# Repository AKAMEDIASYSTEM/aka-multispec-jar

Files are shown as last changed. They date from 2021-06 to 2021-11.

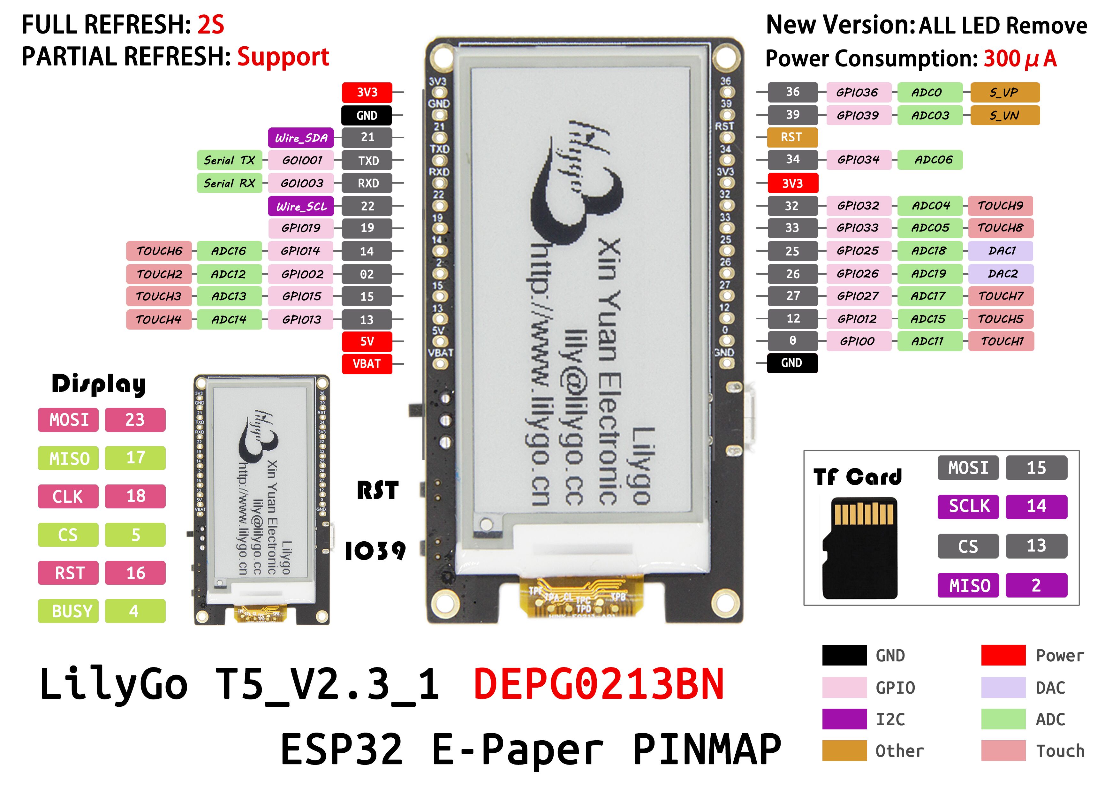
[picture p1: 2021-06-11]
LILYGO-epaper-pinout-graphic.jpg

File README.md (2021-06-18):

EINK STARTER MONITOR
===

See full blogpost [here](https://hi-hi-hi.com/food/projects/2021/06/18/jar.html)

Tracks height of starter with a VL6180 i2c distance sensor, and CO2/temperature/humidity with an SCD30. A small MOSFET circuit drives a little fan to more consistently sample the CO2.

Built around the LILYGO EINK [module](https://www.aliexpress.com/item/32869729970.html)

BOM
-------

- LILYGO EINK [module](https://www.aliexpress.com/item/32869729970.html)
- Adafruit Qwiic [SCD30](https://www.adafruit.com/product/4867)
- Adafruit [VL6180](https://www.adafruit.com/product/3316)
- 2N7000 N-Channel [MOSFET](https://www.digikey.com/en/products/detail/fairchild-semiconductor/2N7000/13430333)
- 420mAh [LiPo](https://www.adafruit.com/product/4236)
- wee tiny Fan ([this](https://www.sparkfun.com/products/15504) or any equivalent, smaller the better)
- M2 screws, 12 to 20mm long, and nuts
- Peanut butter container and 2 lids

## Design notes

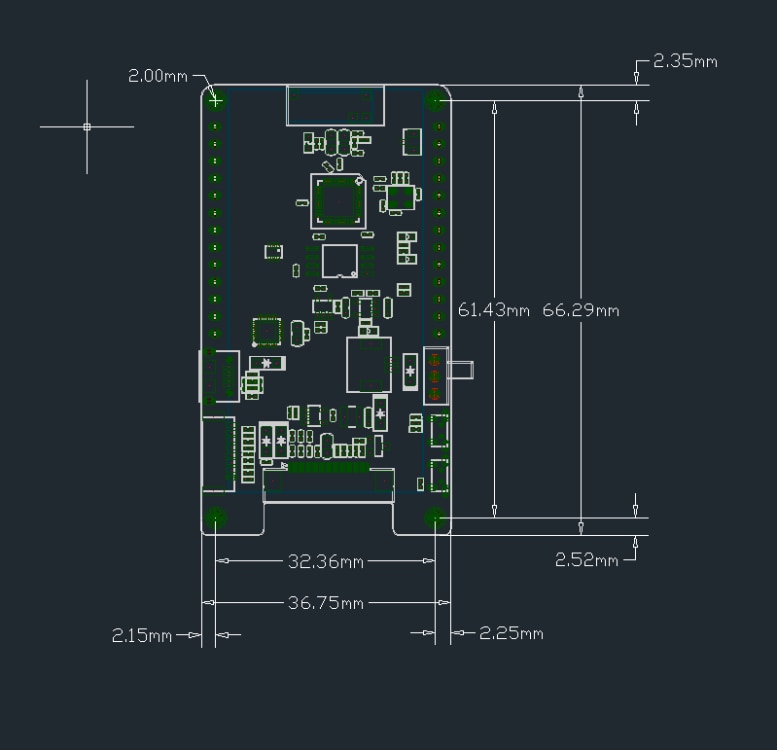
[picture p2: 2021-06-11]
LILYGO-epaper-dimensional.jpg

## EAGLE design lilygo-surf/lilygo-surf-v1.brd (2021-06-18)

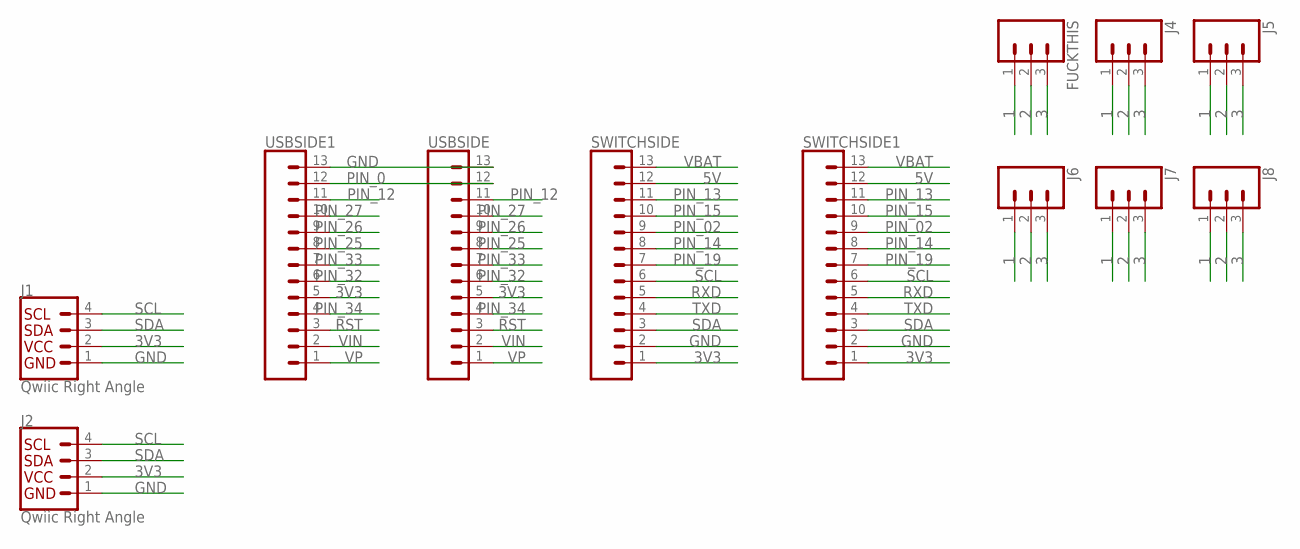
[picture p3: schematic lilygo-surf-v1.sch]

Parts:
FUCKTHIS: CONN_03; 1X03
J1, J2: Qwiic Right Angle; 1X04_1MM_RA
J4, J5, J6, J7, J8: CONN_03; 1X03
SWITCHSIDE, SWITCHSIDE1: CONN_13LOCK; 1X13_LOCK
USBSIDE, USBSIDE1: CONN_13LOCK; 1X13_LOCK

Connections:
1: FUCKTHIS.1, J4.1, J5.1, J6.1, J7.1, J8.1
2: FUCKTHIS.2, J4.2, J5.2, J6.2, J7.2, J8.2
3: FUCKTHIS.3, J4.3, J5.3, J6.3, J7.3, J8.3
3V3: J1.2, J2.2, SWITCHSIDE.1, SWITCHSIDE1.1, USBSIDE.5, USBSIDE1.5
5V: SWITCHSIDE.12, SWITCHSIDE1.12
GND: J1.1, J2.1, SWITCHSIDE.2, SWITCHSIDE1.2, USBSIDE.13, USBSIDE1.13
PIN_0: USBSIDE.12, USBSIDE1.12
PIN_02: SWITCHSIDE.9, SWITCHSIDE1.9
PIN_12: USBSIDE.11, USBSIDE1.11
PIN_13: SWITCHSIDE.11, SWITCHSIDE1.11
PIN_14: SWITCHSIDE.8, SWITCHSIDE1.8
PIN_15: SWITCHSIDE.10, SWITCHSIDE1.10
PIN_19: SWITCHSIDE.7, SWITCHSIDE1.7
PIN_25: USBSIDE.8, USBSIDE1.8
PIN_26: USBSIDE.9, USBSIDE1.9
PIN_27: USBSIDE.10, USBSIDE1.10
PIN_32: USBSIDE.6, USBSIDE1.6
PIN_33: USBSIDE.7, USBSIDE1.7
PIN_34: USBSIDE.4, USBSIDE1.4
RST: USBSIDE.3, USBSIDE1.3
RXD: SWITCHSIDE.5, SWITCHSIDE1.5
SCL: J1.4, J2.4, SWITCHSIDE.6, SWITCHSIDE1.6
SDA: J1.3, J2.3, SWITCHSIDE.3, SWITCHSIDE1.3
TXD: SWITCHSIDE.4, SWITCHSIDE1.4
VBAT: SWITCHSIDE.13, SWITCHSIDE1.13
VIN: USBSIDE.2, USBSIDE1.2
VP: USBSIDE.1, USBSIDE1.1

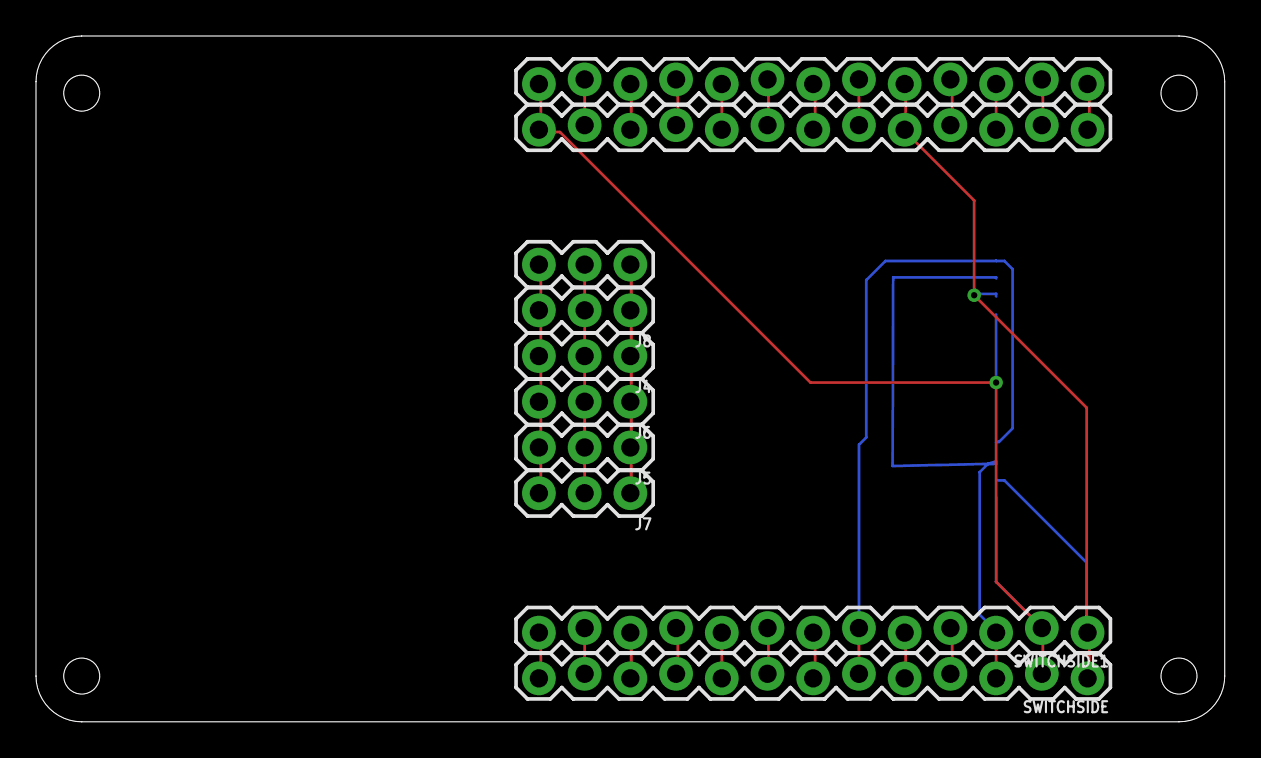
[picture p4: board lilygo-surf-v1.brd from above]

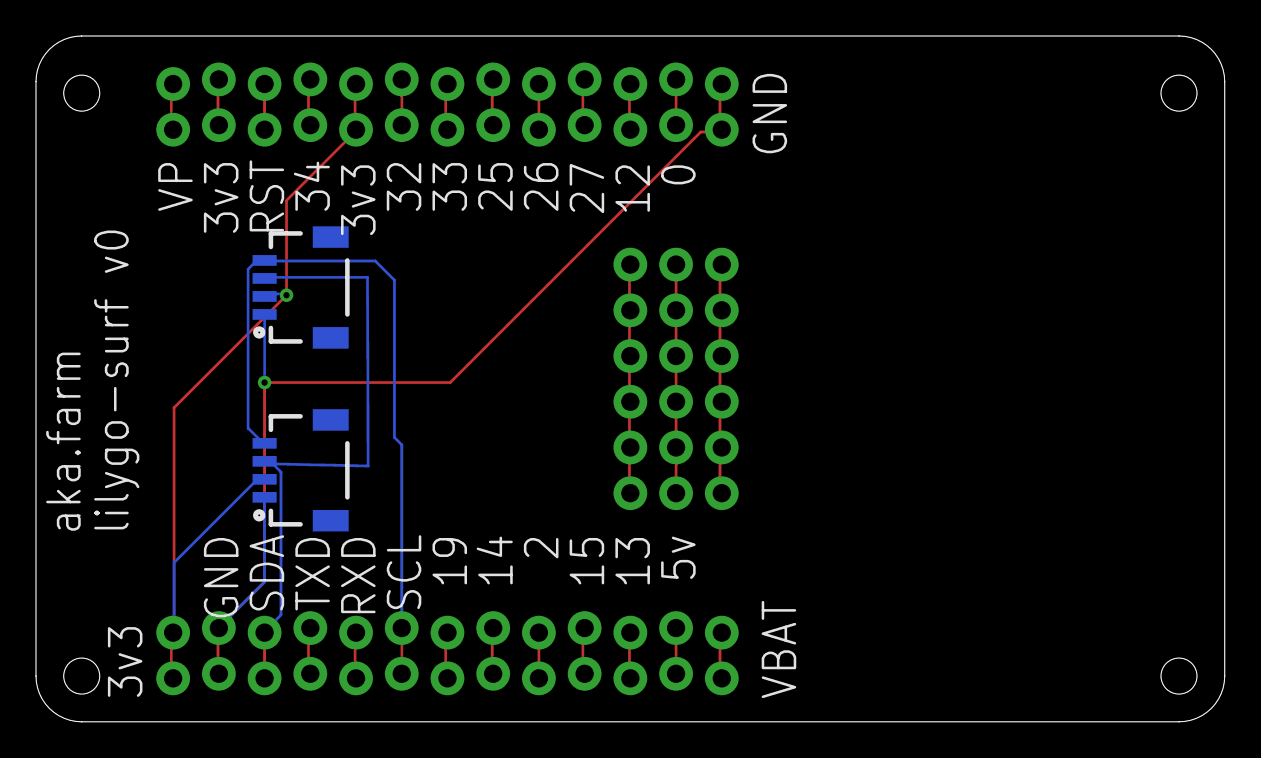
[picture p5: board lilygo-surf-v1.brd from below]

Board: 2 copper layers, 66.0 x 38.1 mm, 12 parts (2 on the bottom side), 27 nets.

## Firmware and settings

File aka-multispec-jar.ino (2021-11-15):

#include <Arduino_JSON.h>

#include <AsyncTCP.h>

#include <AsyncMqttClient.h>

/*
   AKA E-Ink ESP32 Starter Jar

   Monitor starter params


   Update via MQTT to web when possible


   Accept "I fed you" user input buttonpress

   LED PIN is 19, active LOW
   Button pin is 39,
   Has an ADC on pin 35

  series1 - distance in mm from underside of lid to target (from VL6180 over i2c)
  series2 - co2 ppm (from SCD30 over i2c)
  series3 - temp ºC (from SHT3 onboard SCD30)
  series4 - percent humidity (from SHT3 onboard SCD30)


*/
/****************************************************************************************************************************
  Async_ConfigOnStartup.ino
  For ESP8266 / ESP32 boards

  ESPAsync_WiFiManager is a library for the ESP8266/Arduino platform, using (ESP)AsyncWebServer to enable easy
  configuration and reconfiguration of WiFi credentials using a Captive Portal.

  Modified from
  1. Tzapu               (https://github.com/tzapu/WiFiManager)
  2. Ken Taylor          (https://github.com/kentaylor)
  3. Alan Steremberg     (https://github.com/alanswx/ESPAsyncWiFiManager)
  4. Khoi Hoang          (https://github.com/khoih-prog/ESP_WiFiManager)

  Built by Khoi Hoang https://github.com/khoih-prog/ESPAsync_WiFiManager
  Licensed under MIT license
  Version: 1.6.1

  Version Modified By  Date      Comments
  ------- -----------  ---------- -----------
  1.0.11  K Hoang      21/08/2020 Initial coding to use (ESP)AsyncWebServer instead of (ESP8266)WebServer. Bump up to v1.0.11
                                  to sync with ESP_WiFiManager v1.0.11
  1.1.1   K Hoang      29/08/2020 Add MultiWiFi feature to autoconnect to best WiFi at runtime to sync with
                                  ESP_WiFiManager v1.1.1. Add setCORSHeader function to allow flexible CORS
  1.1.2   K Hoang      17/09/2020 Fix bug in examples.
  1.2.0   K Hoang      15/10/2020 Restore cpp code besides Impl.h code to use if linker error. Fix bug.
  1.3.0   K Hoang      04/12/2020 Add LittleFS support to ESP32 using LITTLEFS Library
  1.4.0   K Hoang      18/12/2020 Fix staticIP not saved. Add functions. Add complex examples.
  1.4.1   K Hoang      21/12/2020 Fix bug and compiler warnings.
  1.4.2   K Hoang      21/12/2020 Fix examples' bug not using saved WiFi Credentials after losing all WiFi connections.
  1.4.3   K Hoang      23/12/2020 Fix examples' bug not saving Static IP in certain cases.
  1.5.0   K Hoang      13/02/2021 Add support to new ESP32-S2. Optimize code.
  1.6.0   K Hoang      25/02/2021 Fix WiFi Scanning bug.
  1.6.1   K Hoang      26/03/2021 Modify multiWiFi-related timings to work better with latest esp32 core v1.0.6
 *****************************************************************************************************************************/
/****************************************************************************************************************************
   This example will open a configuration portal for 60 seconds when first powered up if the boards has stored WiFi Credentials.
   Otherwise, it'll stay indefinitely in ConfigPortal until getting WiFi Credentials and connecting to WiFi

   ConfigOnSwitch is a a bettter example for most situations but this has the advantage
   that no pins or buttons are required on the ESP32/ESP8266 device at the cost of delaying
   the user sketch for the period that the configuration portal is open.

   Also in this example a password is required to connect to the configuration portal
   network. This is inconvenient but means that only those who know the password or those
   already connected to the target WiFi network can access the configuration portal and
   the WiFi network credentials will be sent from the browser over an encrypted connection and
   can not be read by observers.
 *****************************************************************************************************************************/

#if !( defined(ESP8266) ||  defined(ESP32) )
#error This code is intended to run on the ESP8266 or ESP32 platform! Please check your Tools->Board setting.
#endif

#define ESP_ASYNC_WIFIMANAGER_VERSION_MIN_TARGET     "ESPAsync_WiFiManager v1.6.1"

// Use from 0 to 4. Higher number, more debugging messages and memory usage.
#define _ESPASYNC_WIFIMGR_LOGLEVEL_    3

//For ESP32, To use ESP32 Dev Module, QIO, Flash 4MB/80MHz, Upload 921600

//Ported to ESP32
#ifdef ESP32
#include <esp_wifi.h>
#include <WiFi.h>
#include <WiFiClient.h>

// From v1.1.1
#include <WiFiMulti.h>
WiFiMulti wifiMulti;

// LittleFS has higher priority than SPIFFS
#define USE_LITTLEFS    true
#define USE_SPIFFS      false
#if USE_LITTLEFS
// Use LittleFS
#include "FS.h"

// The library will be depreciated after being merged to future major Arduino esp32 core release 2.x
// At that time, just remove this library inclusion
#include <LITTLEFS.h>             // https://github.com/lorol/LITTLEFS

FS* filesystem =      &LITTLEFS;
#define FileFS        LITTLEFS
#define FS_Name       "LittleFS"
#elif USE_SPIFFS
#include <SPIFFS.h>
FS* filesystem =      &SPIFFS;
#define FileFS        SPIFFS
#define FS_Name       "SPIFFS"
#else
// Use FFat
#include <FFat.h>
FS* filesystem =      &FFat;
#define FileFS        FFat
#define FS_Name       "FFat"
#endif
//////

#define ESP_getChipId()   ((uint32_t)ESP.getEfuseMac())

#define LED_BUILTIN       2
#define LED_ON            HIGH
#define LED_OFF           LOW

#else
#include <ESP8266WiFi.h>          //https://github.com/esp8266/Arduino
//needed for library
#include <DNSServer.h>

// From v1.1.0
#include <ESP8266WiFiMulti.h>
ESP8266WiFiMulti wifiMulti;

#define USE_LITTLEFS      true

#if USE_LITTLEFS
#include <LittleFS.h>
FS* filesystem = &LittleFS;
#define FileFS    LittleFS
#define FS_Name       "LittleFS"
#else
FS* filesystem = &SPIFFS;
#define FileFS    SPIFFS
#define FS_Name       "SPIFFS"
#endif
//////

#define ESP_getChipId()   (ESP.getChipId())

#define LED_ON      LOW
#define LED_OFF     HIGH
#endif

#include <GxEPD.h>
#include "SD.h"
#include "SPI.h"
#include "Adafruit_VL6180X.h"
#include <Adafruit_SCD30.h>
Adafruit_SCD30 scd;
Adafruit_VL6180X vl = Adafruit_VL6180X();
// HEY HEY HEY IT'S Trotz Idee
/*
  · Operating voltage: 3.3V
  · Interface: 3-wire SPI, 4-wire SPI
  · Display color:  black, white
  · Grey level: 2
  · Full refresh time: 8s
  · Refresh power: 26.4mW(typ.)
  - Resolution 250x122
  Driver chip：SSD1680Z8
*/
//#include <GxGDEH0213B73/GxGDEH0213B73.h>  // 2.13" b/w newer panel THIS ONE IS AKA LILYGO JAN 2021
#include <GxDEPG0213BN/GxDEPG0213BN.h> // this is the newer, May 2021 board with no LEDs onboard
// FreeFonts from Adafruit_GFX
#include <Fonts/FreeMonoBold9pt7b.h>
#include <Fonts/FreeMonoBold12pt7b.h>
#include <Fonts/FreeMonoBold18pt7b.h>
#include <Fonts/FreeMonoBold24pt7b.h>
#include <Fonts/FreeSansBold9pt7b.h>
#include <Fonts/FreeSansBold12pt7b.h>
#include <Fonts/FreeSansBold18pt7b.h>
#include <Fonts/FreeSansBold24pt7b.h>
#include <Fonts/FreeSans9pt7b.h>
#include <Fonts/FreeSans12pt7b.h>
#include <Fonts/FreeSans18pt7b.h>
#include <Fonts/FreeSans24pt7b.h>
#include <Fonts/FreeSansBoldOblique9pt7b.h>
#include <Fonts/FreeSansBoldOblique12pt7b.h>
#include <Fonts/FreeSansBoldOblique18pt7b.h>
#include <Fonts/FreeSansBoldOblique24pt7b.h>
#include <Fonts/FreeSerif9pt7b.h>
#include <Fonts/FreeSerif12pt7b.h>
#include <Fonts/FreeSerif18pt7b.h>
#include <Fonts/FreeSerif24pt7b.h>
#include <Fonts/Picopixel.h>
#include <Fonts/Org_01.h>
#include <GxIO/GxIO_SPI/GxIO_SPI.h>
#include <GxIO/GxIO.h>

// PINS
#define SPI_MOSI 23
#define SPI_MISO -1
#define SPI_CLK 18
#define ELINK_SS 5
#define ELINK_BUSY 4
#define ELINK_RESET 16
#define ELINK_DC 17
#define SDCARD_SS 13
#define SDCARD_CLK 14
#define SDCARD_MOSI 15
#define SDCARD_MISO 2
#define BUTTON_PIN 39
#define FAN_PIN 12


// DISPLAY PARAMS
#define MARGIN 5
#define GRAPH_W 225
#define GRAPH_H 40
#define GRAPH_Y 40
#define GRAPH_X 25
#define NAME_X 0
#define NAME_W 150
#define NAME_Y 15
#define NAME_H 30
#define TREND_X 225
#define TREND_W 25
#define TREND_Y 25
#define TREND_H 50
int startX = 5;
int startY = 5;

// DATA AND TIMING PARAMS
#define FRIDGE_THRESHOLD_TEMPERATURE 8 // at what ºC do we assume we are in fridge
#define SAMPLE_DEPTH 225  // this is determined by GRAPH_W or how good you want your data to be
#define DISPLAY_UPDATE_LOOPS 3  // don't update every loop; update every X loops
#define SENSOR_MAX 2048
#define TICK_INTERVAL 15  // every n samples, we have a "tick" for visual distinction. 
#define LOOP_DELAY_SECS 60  // sample once per minute; tick-to-tick interval is 16 minutes; total graph shows last 3.75h
#define FAN_DURATION_MS 10000 // length of time DURING the sampler() function that fan runs before we read the sensors
#define VERBOSE 0
#define DEBUG 1
#define PORTAL_TIMEOUT 30  // host own AP for PORTAL_TIMEOUT seconds before joining wifi using any saved credentials

//const char *starterName = "LENNY-FANNY"; // this one should be jar/FAC40A24
//const char *starterName = "LENNY-GASSY";  // this one should be jar/60A8CC84
String starterName = "10s fan " + String(ESP_getChipId(), HEX);

#ifndef _swap_int16_t
#define _swap_int16_t(a, b)                                                    \
  {                                                                            \
    int16_t t = a;                                                             \
    a = b;                                                                     \
    b = t;                                                                     \
  }
#endif
#ifndef min
#define min(a, b) (((a) < (b)) ? (a) : (b))
#endif

GxIO_Class io(SPI, /*CS=5*/ ELINK_SS, /*DC=*/ ELINK_DC, /*RST=*/ ELINK_RESET);
GxEPD_Class display(io, /*RST=*/ ELINK_RESET, /*BUSY=*/ ELINK_BUSY);
SPIClass sdSPI(VSPI);
int bmpWidth = 150, bmpHeight = 39;

// VL6180 distance sensor (mm)
int series1[SAMPLE_DEPTH] = {0};
int series1der[SAMPLE_DEPTH] = {0};
int series1max = 0;
int series1min = 2000;
int series1max_h = 0; // _h means all-time max and min
int series1min_h = 2000; // _h means all-time max and min
int series1dermin = 0;
int series1dermax = 0;
// if the range of the series is less than this we display a flattened graph
// pick a sensor-dependent value above noise floor
int SERIES1_SIGNIFICANCE_THRESHOLD = 12;

// SCD30 CO2 sensor (ppm)
int series2[SAMPLE_DEPTH] = {0};
int series2der[SAMPLE_DEPTH] = {0};
int series2max = 0;
int series2min = 2000;
int series2max_h = 0; // _h means all-time max and min
int series2min_h = 2000; // _h means all-time max and min
int series2dermin = 0;
int series2dermax = 0;
int SERIES2_SIGNIFICANCE_THRESHOLD = 10;

// SCD30 Temperature Sensor (C)
int series3[SAMPLE_DEPTH] = {0};
int series3der[SAMPLE_DEPTH] = {0};
int series3max = 0;
int series3min = 2000;
int series3max_h = 0; // _h means all-time max and min
int series3min_h = 2000; // _h means all-time max and min
int series3dermin = 0;
int series3dermax = 0;
int SERIES3_SIGNIFICANCE_THRESHOLD = 10;

// SCD30 Relative Humidity Sensor (percent)
int series4[SAMPLE_DEPTH] = {0};
int series4der[SAMPLE_DEPTH] = {0};
int series4max = 0;
int series4min = 2000;
int series4max_h = 0; // _h means all-time max and min
int series4min_h = 2000; // _h means all-time max and min
int series4dermin = 0;
int series4dermax = 0;
int SERIES4_SIGNIFICANCE_THRESHOLD = 10;

bool sdOK = false;
bool firstReading = true;
unsigned int distance = 0;
unsigned int gas = 0;
int sc = 0;

// SSID and PW for Config Portal
String ssid = "aka_" + String(ESP_getChipId(), HEX);
const char* password = "boysboysboys";

// SSID and PW for your Router
String Router_SSID;
String Router_Pass;

// From v1.1.1
// You only need to format the filesystem once
//#define FORMAT_FILESYSTEM       true
#define FORMAT_FILESYSTEM         false

#define MIN_AP_PASSWORD_SIZE    8

#define SSID_MAX_LEN            32
//From v1.0.10, WPA2 passwords can be up to 63 characters long.
#define PASS_MAX_LEN            64

typedef struct
{
  char wifi_ssid[SSID_MAX_LEN];
  char wifi_pw  [PASS_MAX_LEN];
}  WiFi_Credentials;

typedef struct
{
  String wifi_ssid;
  String wifi_pw;
}  WiFi_Credentials_String;

#define NUM_WIFI_CREDENTIALS      2

typedef struct
{
  WiFi_Credentials  WiFi_Creds [NUM_WIFI_CREDENTIALS];
} WM_Config;

WM_Config         WM_config;

#define  CONFIG_FILENAME              F("/wifi_cred.dat")
//////

// Indicates whether ESP has WiFi credentials saved from previous session, or double reset detected
bool initialConfig = false;

// Use false if you don't like to display Available Pages in Information Page of Config Portal
// Comment out or use true to display Available Pages in Information Page of Config Portal
// Must be placed before #include <ESP_WiFiManager.h>
#define USE_AVAILABLE_PAGES     true

// From v1.0.10 to permit disable/enable StaticIP configuration in Config Portal from sketch. Valid only if DHCP is used.
// You'll loose the feature of dynamically changing from DHCP to static IP, or vice versa
// You have to explicitly specify false to disable the feature.
//#define USE_STATIC_IP_CONFIG_IN_CP          false

// Use false to disable NTP config. Advisable when using Cellphone, Tablet to access Config Portal.
// See Issue 23: On Android phone ConfigPortal is unresponsive (https://github.com/khoih-prog/ESP_WiFiManager/issues/23)
#define USE_ESP_WIFIMANAGER_NTP     false

// Use true to enable CloudFlare NTP service. System can hang if you don't have Internet access while accessing CloudFlare
// See Issue #21: CloudFlare link in the default portal (https://github.com/khoih-prog/ESP_WiFiManager/issues/21)
#define USE_CLOUDFLARE_NTP          false

// New in v1.0.11
#define USING_CORS_FEATURE          true
//////
// Use USE_DHCP_IP == true for dynamic DHCP IP, false to use static IP which you have to change accordingly to your network
#if (defined(USE_STATIC_IP_CONFIG_IN_CP) && !USE_STATIC_IP_CONFIG_IN_CP)
// Force DHCP to be true
#if defined(USE_DHCP_IP)
#undef USE_DHCP_IP
#endif
#define USE_DHCP_IP     true
#else
// You can select DHCP or Static IP here
#define USE_DHCP_IP     true
//#define USE_DHCP_IP     false
#endif

#if ( USE_DHCP_IP )
// Use DHCP
#warning Using DHCP IP
IPAddress stationIP   = IPAddress(0, 0, 0, 0);
IPAddress gatewayIP   = IPAddress(192, 168, 0, 1);
IPAddress netMask     = IPAddress(255, 255, 255, 0);
#else
// Use static IP
#warning Using static IP

#ifdef ESP32
IPAddress stationIP   = IPAddress(192, 168, 1, 132);
#else
IPAddress stationIP   = IPAddress(192, 168, 2, 186);
#endif

IPAddress gatewayIP   = IPAddress(192, 168, 0, 1);
IPAddress netMask     = IPAddress(255, 255, 255, 0);
#endif

#define USE_CONFIGURABLE_DNS      true

IPAddress dns1IP      = gatewayIP;
IPAddress dns2IP      = IPAddress(8, 8, 8, 8);

IPAddress APStaticIP  = IPAddress(192, 168, 101, 1);
IPAddress APStaticGW  = IPAddress(192, 168, 101, 1);
IPAddress APStaticSN  = IPAddress(255, 255, 255, 0);

#include <ESPAsync_WiFiManager.h>              //https://github.com/khoih-prog/ESPAsync_WiFiManager

#define HTTP_PORT     80

const int PIN_LED = 2; // D4 on NodeMCU and WeMos. GPIO2/ADC12 of ESP32. Controls the onboard LED.

//  AKA MQTT attempts
AsyncMqttClient mqttClient;
IPAddress MQTT_HOST      = IPAddress(192, 168, 0, 105);
#define MQTT_PORT 1883
String topicString = String(ESP_getChipId(), HEX);


///////////////////////////////////////////
// New in v1.4.0
/******************************************
   // Defined in ESPAsync_WiFiManager.h
  typedef struct
  {
  IPAddress _ap_static_ip;
  IPAddress _ap_static_gw;
  IPAddress _ap_static_sn;

  }  WiFi_AP_IPConfig;

  typedef struct
  {
  IPAddress _sta_static_ip;
  IPAddress _sta_static_gw;
  IPAddress _sta_static_sn;
  #if USE_CONFIGURABLE_DNS
  IPAddress _sta_static_dns1;
  IPAddress _sta_static_dns2;
  #endif
  }  WiFi_STA_IPConfig;
******************************************/

WiFi_AP_IPConfig  WM_AP_IPconfig;
WiFi_STA_IPConfig WM_STA_IPconfig;


///////////////////////////////////////////





void setup()
{
  pinMode(FAN_PIN, OUTPUT);
  pinMode(LED_BUILTIN, OUTPUT);
  Serial.begin(115200);
  while (!Serial);

  delay(200); // for Serial
  topicString.toUpperCase();
  starterName.toUpperCase();
  SPI.begin(SPI_CLK, SPI_MISO, SPI_MOSI, ELINK_SS);
  display.init(); // enable diagnostic output on Serial
  display.setRotation(1);
  display.fillScreen(GxEPD_WHITE);
  display.setTextColor(GxEPD_BLACK);
  display.setFont(&FreeMonoBold9pt7b);
  display.setCursor(0, 0);
  Serial.println("setup: AKA-JAR");
  initSensors();
  display.fillScreen(GxEPD_WHITE);
  display.setTextColor(GxEPD_BLACK);
  display.setCursor(NAME_X, NAME_Y);
  display.setFont(&FreeSansBoldOblique9pt7b);
  display.print(starterName);
  stopFan();
  clobber(true);
  // display.update();
  // goto sleep
  //  esp_sleep_enable_ext0_wakeup((gpio_num_t)BUTTON_PIN, LOW);
  //  esp_deep_sleep_start();


  Serial.print(F("\nStarting Async_ConfigOnStartup using ")); Serial.print(FS_Name);
  Serial.print(F(" on ")); Serial.println(ARDUINO_BOARD);
  Serial.println(ESP_ASYNC_WIFIMANAGER_VERSION);

  if ( String(ESP_ASYNC_WIFIMANAGER_VERSION) < ESP_ASYNC_WIFIMANAGER_VERSION_MIN_TARGET )
  {
    Serial.print("Warning. Must use this example on Version later than : ");
    Serial.println(ESP_ASYNC_WIFIMANAGER_VERSION_MIN_TARGET);
  }

  Serial.setDebugOutput(false);

  if (FORMAT_FILESYSTEM)
    FileFS.format();

  // Format FileFS if not yet
#ifdef ESP32
  if (!FileFS.begin(true))
#else
  if (!FileFS.begin())
#endif
  {
    Serial.print(FS_Name);
    Serial.println(F(" failed! AutoFormatting."));

#ifdef ESP8266
    FileFS.format();
#endif
  }

  unsigned long startedAt = millis();

  // New in v1.4.0
  initAPIPConfigStruct(WM_AP_IPconfig);
  initSTAIPConfigStruct(WM_STA_IPconfig);
  //////

  //Local intialization. Once its business is done, there is no need to keep it around
  // Use this to default DHCP hostname to ESP8266-XXXXXX or ESP32-XXXXXX
  //ESPAsync_WiFiManager ESPAsync_wifiManager(&webServer, &dnsServer);
  // Use this to personalize DHCP hostname (RFC952 conformed)
  AsyncWebServer webServer(HTTP_PORT);

#if ( ARDUINO_ESP32S2_DEV || ARDUINO_FEATHERS2 || ARDUINO_PROS2 || ARDUINO_MICROS2 )
  ESPAsync_WiFiManager ESPAsync_wifiManager(&webServer, NULL, starterName.c_str()); // c_str() converts string into const char
#else
  DNSServer dnsServer;

  ESPAsync_WiFiManager ESPAsync_wifiManager(&webServer, &dnsServer, starterName.c_str());
#endif

  //set custom ip for portal
  // New in v1.4.0
  ESPAsync_wifiManager.setAPStaticIPConfig(WM_AP_IPconfig);
  //////

  ESPAsync_wifiManager.setMinimumSignalQuality(-1);

  // From v1.0.10 only
  // Set config portal channel, default = 1. Use 0 => random channel from 1-13
  ESPAsync_wifiManager.setConfigPortalChannel(0);
  //////
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
void loop()
{
  check_status();

  // sample every LOOP_DELAY seconds
  sampler();
  if (!inFridge()) {
    publishMQTT();
  }
  // update the screen every DISPLAY_UPDATE_LOOPs
  sc++;
  if (sc == DISPLAY_UPDATE_LOOPS) {
    if (DEBUG) {
      Serial.println("UPDATE_SCREEN triggered");
    }
    sc = 0;
    display.fillScreen(GxEPD_WHITE);
    // drawGraph();
    // drawGraph2(int series[], int seriesDepth, int sx, int sy, int sh, int sw, int s_min, int s_max, int s_thresh) {
    //    drawGraph2(series1, SAMPLE_DEPTH, 25, GRAPH_H*3, GRAPH_H, GRAPH_W, series1min, series1max, SERIES1_SIGNIFICANCE_THRESHOLD);
    //    drawGraph2(series2, SAMPLE_DEPTH, 25, GRAPH_H*2, GRAPH_H, GRAPH_W, series2min, series2max, SERIES2_SIGNIFICANCE_THRESHOLD);
    drawGraph2(series1, SAMPLE_DEPTH, 25, (GRAPH_H * 2), GRAPH_H, GRAPH_W, 50, 200, SERIES1_SIGNIFICANCE_THRESHOLD);
    drawGraph2(series2, SAMPLE_DEPTH, 25, GRAPH_H, GRAPH_H, GRAPH_W, 400, 2000, SERIES2_SIGNIFICANCE_THRESHOLD);
    drawTrend();
    drawName();
    // display.updateWindow(0, 0, GxEPD_WIDTH, GxEPD_HEIGHT, false);
    display.update();
  }

  if (VERBOSE) {
    Serial.print("Series1 max/min this 15-loop are: ");
    Serial.print(series1max);
    Serial.print(" ");
    Serial.println(series1min);

    Serial.print("Series2 max/min this 15-loop are: ");
    Serial.print(series2max);
    Serial.print(" ");
    Serial.println(series2min);

    Serial.print("Series3 max/min this 15-loop are: ");
    Serial.print(series3max);
    Serial.print(" ");
    Serial.println(series3min);

    Serial.print("Series4 max/min this 15-loop are: ");
    Serial.print(series4max);
    Serial.print(" ");
    Serial.println(series4min);
  }

  // blocking delay() until next sample; this should all be interrupt-timer driven
  delay(LOOP_DELAY_SECS * 1000);
}

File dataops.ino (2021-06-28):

float summarize(int series[], int farback) {
  float slope = ((series[0] - series[farback - 1]) / farback);
  return slope;
}

void initSensors() {
  if (! vl.begin()) {
    Serial.println("Sensor VL6180 not found :(");
    delay(1000);
  } else {
    Serial.println("Sensor VL6180 online");
  }

  if (!scd.begin()) {
    Serial.println("Sensor SCD30 not found :(");
    delay(1000);
  } else {
    Serial.println("Sensor SCD30 online");
  }
}

int maxOf(int series[], int seriesDepth) {
  int theMax = -200000;
  for (int i = 0; i < seriesDepth; i++) {
    if (series[i] > theMax) {
      theMax = series[i];
    }
  }
  return theMax;
}

int minOf(int series[], int seriesDepth) {
  int theMin = 200000;
  for (int i = 0; i < seriesDepth; i++) {
    if (series[i] < theMin) {
      theMin = series[i];
    }
  }
  return theMin;
}

void backfill(int series[], int theVal) {
  for (int i = 0; i < SAMPLE_DEPTH; i++) {
    series[i] = theVal;
  }
}

void clobber(bool shouldZero) {
  // fill timeseries with dummy init data for debugging purposes
  for (int i = 0; i < SAMPLE_DEPTH; i++) {
    if (shouldZero) {
      series1[i] = 0;
      series2[i] = 0;
    } else {
      series1[i] = random(0, 200);
      series2[i] = random(400, 2000);
    }
  }
  if (DEBUG) {
    Serial.print("Clobbered all data ");
    (shouldZero ? Serial.println("into zeroes") : Serial.println("into random"));
  }
}

void startFan() {
  digitalWrite(FAN_PIN, HIGH);
  if (DEBUG) {
    Serial.println("FAN ON");
  }
}

void stopFan() {
  digitalWrite(FAN_PIN, LOW);
  if (DEBUG) {
    Serial.println("FAN OFF");
  }
}

void sampler() {
  int distance = 0;
  int gas = 0;
  int rh = 0;
  int tmp = 0;

  startFan();
  delay(FAN_DURATION_MS);

  if (VERBOSE) {
    Serial.print("inside sampler, series1[0] is ");
    Serial.println(series1[0]);
  }
  uint8_t range = vl.readRange();
  uint8_t status = vl.readRangeStatus();

  if (status == VL6180X_ERROR_NONE) {
    distance = range;
  }
  if (VERBOSE) {
    Serial.print("VL6180 distance is: ");
    Serial.println(distance);
  }
  if ((status >= VL6180X_ERROR_SYSERR_1) && (status <= VL6180X_ERROR_SYSERR_5)) {
    Serial.println("VL6180X_ERROR error");
  }
  else if (status == VL6180X_ERROR_ECEFAIL) {
    Serial.println("VL6180X_ERROR ECE failure");
  }
  else if (status == VL6180X_ERROR_NOCONVERGE) {
    Serial.println("VL6180X_ERROR No convergence");
  }
  else if (status == VL6180X_ERROR_RANGEIGNORE) {
    Serial.println("VL6180X_ERROR Ignoring range");
  }
  else if (status == VL6180X_ERROR_SNR) {
    Serial.println("VL6180X_ERROR Signal/Noise error");
  }
  else if (status == VL6180X_ERROR_RAWUFLOW) {
    Serial.println("Raw reading underflow");
  }
  else if (status == VL6180X_ERROR_RAWOFLOW) {
    Serial.println("VL6180X_ERROR Raw reading overflow");
  }
  else if (status == VL6180X_ERROR_RANGEUFLOW) {
    Serial.println("VL6180X_ERROR Range reading underflow");
  }
  else if (status == VL6180X_ERROR_RANGEOFLOW) {
    Serial.println("VL6180X_ERROR Range reading overflow");
  }
  if (distance > SENSOR_MAX) {
    distance = SENSOR_MAX;
  }
  for (int i = SAMPLE_DEPTH - 2; i >= 0; i--) {
    series1[i + 1] = series1[i];
  }
  series1[0] = distance;
  if (firstReading) {
    //if first reading, backfill the series with this reading for easier graph sizing
    backfill(series1, distance);
  }

  series1max = maxOf(series1, SAMPLE_DEPTH);
  series1min = minOf(series1, SAMPLE_DEPTH);

  if (distance > series1max_h) {
    if (VERBOSE) {
      Serial.print("new series1 historical maximum: ");
      Serial.println(distance);
    }
    series1max_h = distance;
  }
  if (distance < series1min_h) {
    if (VERBOSE) {
      Serial.print("new series1 historical minimum: ");
      Serial.println(distance);
    }
    series1min_h = distance;
  }

  //  if (VERBOSE) {
  //    for (int i = 0; i < SAMPLE_DEPTH; i++) {
  //      Serial.print(series1[i]);
  //      Serial.print(" ");
  //    }
  //    Serial.println();
  //  }

  // SERIES 2 OPERATIONS

  if (scd.dataReady()) {
    if (VERBOSE) {
      Serial.println("Data available!");
    }

    if (!scd.read()) {
      Serial.println("Error reading sensor data");
      return;
    }
    tmp = scd.temperature;
    rh = scd.relative_humidity;
    gas = scd.CO2;
  } else {
    Serial.println("error with scd30, dataReady was false");
  }
  for (int i = SAMPLE_DEPTH - 2; i >= 0; i--) {
    series2[i + 1] = series2[i];
    series3[i + 1] = series3[i];
    series4[i + 1] = series4[i];
  }
  series2[0] = gas;
  series3[0] = tmp;
  series4[0] = rh;

  if (firstReading) {
    //if first reading, backfill the series with this reading for easier graph sizing
    if (DEBUG) {
      Serial.print("firstReading was true, backfilling all the sensors: ");
      Serial.print(distance);
      Serial.print(" ");
      Serial.print(gas);
      Serial.print(" ");
      Serial.print(tmp);
      Serial.print(" ");
      Serial.println(rh);
    }
    backfill(series2, gas);
    backfill(series3, tmp);
    backfill(series4, rh);
    firstReading = false;
  }

  series2max = maxOf(series2, SAMPLE_DEPTH);
  series2min = minOf(series2, SAMPLE_DEPTH);
  series3max = maxOf(series3, SAMPLE_DEPTH);
  series3min = minOf(series3, SAMPLE_DEPTH);
  series4max = maxOf(series4, SAMPLE_DEPTH);
  series4min = minOf(series4, SAMPLE_DEPTH);

  if (gas > series2max_h) {
    if (VERBOSE) {
      Serial.print("new s2 historical maximum: ");
      Serial.println(gas);
    }
    series2max_h = gas;
  }

  if (gas < series2min_h) {
    if (VERBOSE) {
      Serial.print("new s2 historical minimum: ");
      Serial.println(gas);
    }
    series2min_h = gas;
  }

  if (tmp > series3max_h) {
    if (VERBOSE) {
      Serial.print("new s3 historical maximum: ");
      Serial.println(tmp);
    }
    series3max_h = tmp;
  }

  if (tmp < series3min_h) {
    if (VERBOSE) {
      Serial.print("new s3 historical minimum: ");
      Serial.println(tmp);
    }
    series3min_h = tmp;
  }

  if (rh > series4max_h) {
    if (VERBOSE) {
      Serial.print("new s4 historical maximum: ");
      Serial.println(rh);
    }
    series4max_h = rh;
  }

  if (rh < series4min_h) {
    if (VERBOSE) {
      Serial.print("new s4 historical minimum: ");
      Serial.println(rh);
    }
    series4min_h = rh;
  }

  //  if (VERBOSE) {
  //    for (int i = 0; i < SAMPLE_DEPTH; i++) {
  //      Serial.print(series2[i]);
  //      Serial.print(" ");
  //    }
  //    Serial.println();
  //  }

  if (DEBUG) {

    Serial.print("distance is ");
    Serial.print(distance);
    Serial.print(" local min: ");
    Serial.print(series1min);
    Serial.print(" local max: ");
    Serial.print(series1max);
    Serial.print(" historical min: ");
    Serial.print(series1min_h);
    Serial.print(" historical max: ");
    Serial.println(series1max_h);
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

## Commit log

2021-06-06 first commit to this repo. Soon I will remove lots of distance-sensor code.
2021-06-06 updated to track all 4 sensor channels and remove outdated libraries
2021-06-11 removing SD card code, removing qwiic powerswitch hack code, making mqtt topics device-specific
2021-06-11 tested and implemented fan control via 2n7000 mosfet rather than absurd qwiic contrivance. changing MQTT topic names, still not connecting properly to mycodo
2021-06-18 adding PCB
    [lilygo-surf-v1.brd, lilygo-surf-v1.sch]

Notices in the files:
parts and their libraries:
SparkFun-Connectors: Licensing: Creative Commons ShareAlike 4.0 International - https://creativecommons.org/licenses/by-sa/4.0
